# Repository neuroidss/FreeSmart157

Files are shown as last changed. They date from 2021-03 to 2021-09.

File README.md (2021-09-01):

# FreeSmart157

FreeSmartEEG64 prealpha 8 channels assembled
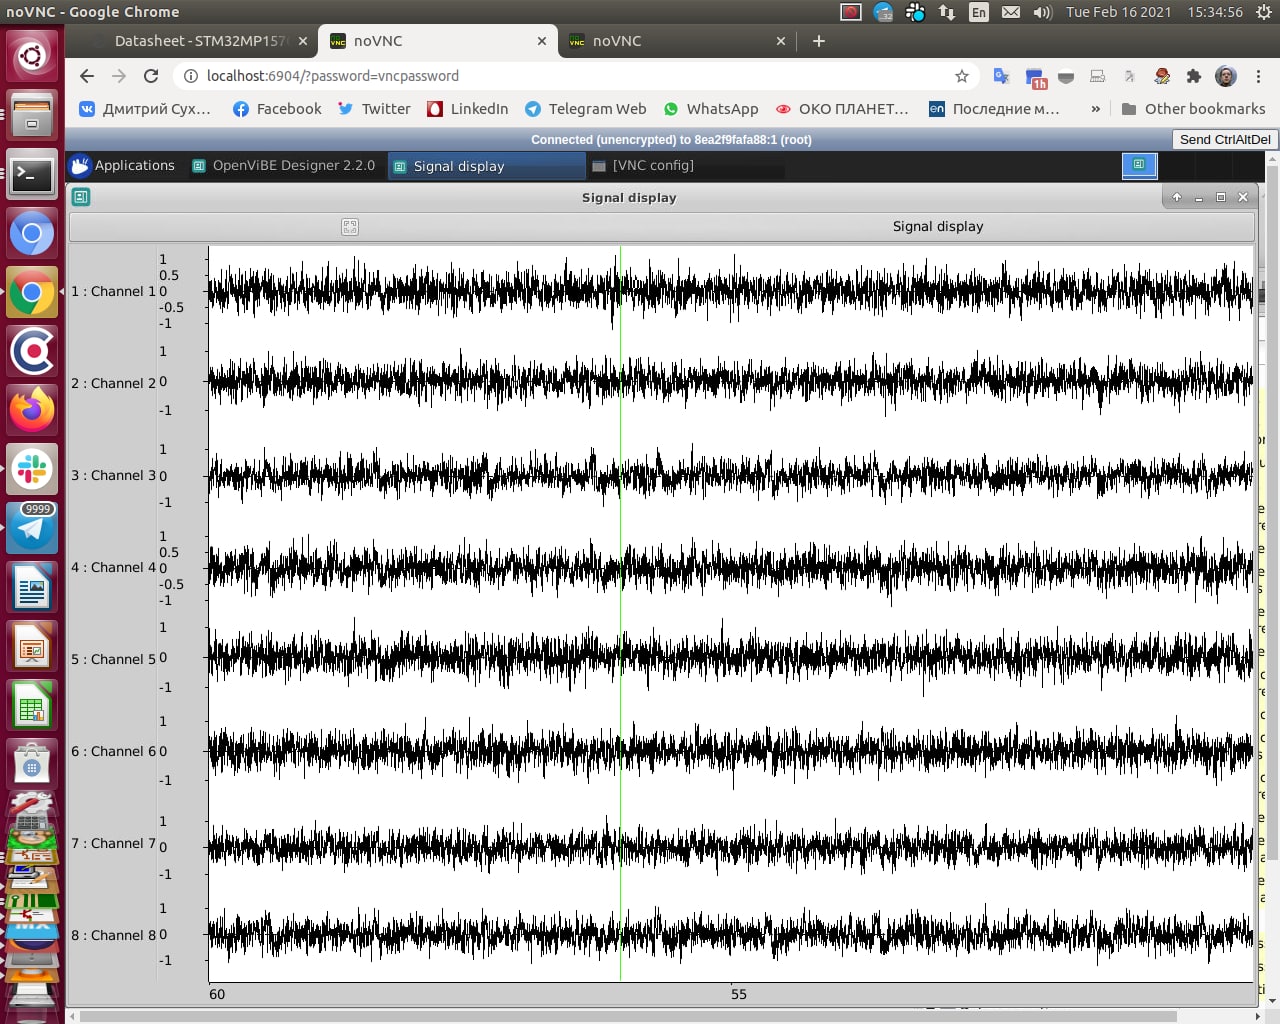
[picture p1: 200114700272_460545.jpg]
FreeSmartEEG64 prealpha 8 channels shorted noise uV AD7771


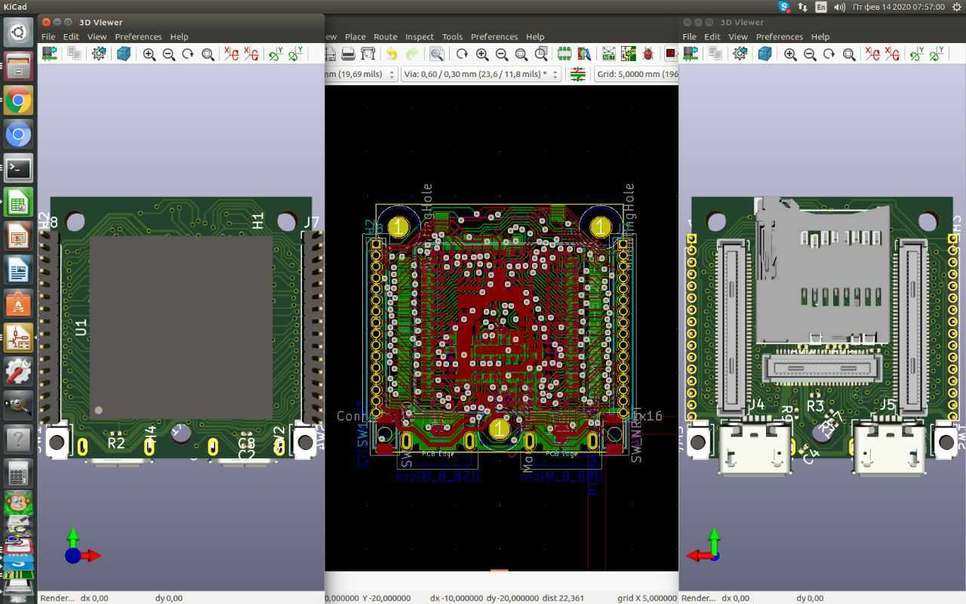
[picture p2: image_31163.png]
FreeSmart157 prealpha module

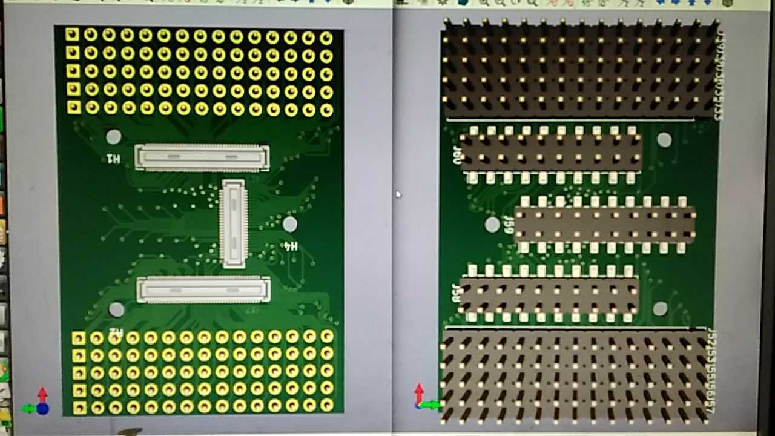
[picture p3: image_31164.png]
FreeSmart157 prealpha devboard


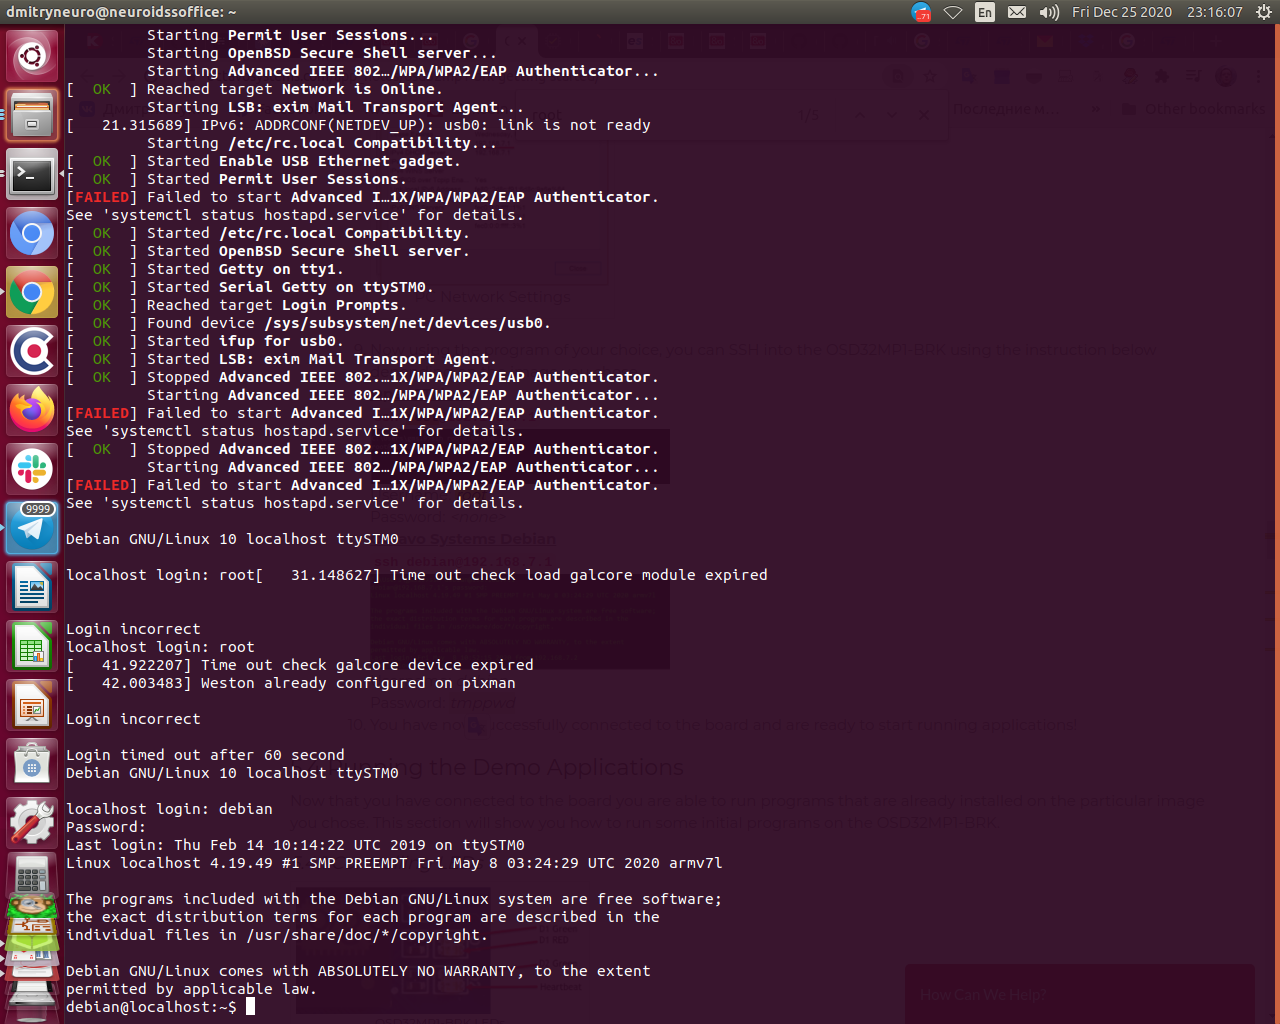
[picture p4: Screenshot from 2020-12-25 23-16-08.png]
FreeSmart157 prealpha debian login

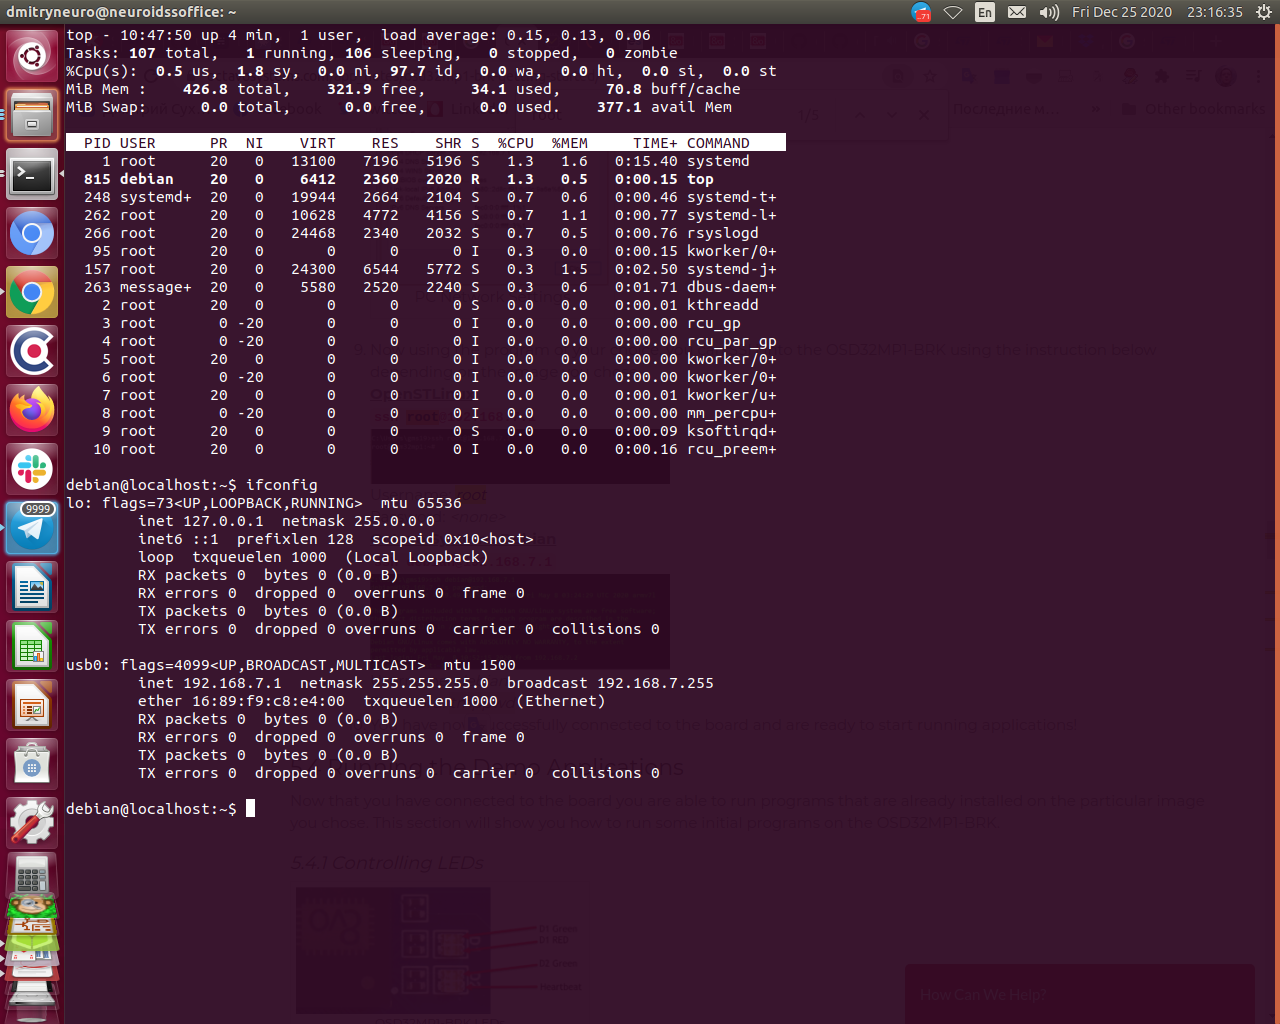
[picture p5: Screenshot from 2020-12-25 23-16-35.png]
FreeSmart157 prealpha top ifconfig


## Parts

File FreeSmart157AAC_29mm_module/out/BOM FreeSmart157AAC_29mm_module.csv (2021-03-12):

Designator | Manufacturer Part Number or Seeed SKU | Qty | Link
SW4,SW3,SW2,SW1 | B3U-1000P | 4 | https://www.digikey.com/product-detail/en/omron-electronics-inc-emc-div/B3U-1000P/SW1020CT-ND/1534357
R9,R13,R12,R10,R4,R3 | RC0201JR-070RL | 6 | https://www.digikey.com/product-detail/en/yageo/RC0201JR-070RL/311-0.0NCT-ND/1949004
P1 | DF40C-50DP-0.4V(51) | 1 | https://www.digikey.com/product-detail/en/hirose-electric-co-ltd/DF40C-50DP-0.4V-51/H11626CT-ND/1969505
U1 | OSD32MP157C-512M-BAA-ES | 1 | https://www.digikey.com/product-detail/en/octavo-systems-llc/OSD32MP157C-512M-BAA-ES/1676-OSD32MP157C-512M-BAA-ES-ND/10481787
J3 | 0473521001 | 1 | https://www.digikey.com/product-detail/en/molex/0473521001/WM3290CT-ND/2405698
C8,C4 | CC0201KRX5R6BB103 | 2 | https://www.digikey.com/product-detail/en/yageo/CC0201KRX5R6BB103/311-1409-1-ND/2833715
R2,R1,R7 | RC0201JR-071KL | 3 | https://www.digikey.com/product-detail/en/yageo/RC0201JR-071KL/311-1KNCT-ND/1949028
C2 | GRM033R60J104KE19D | 1 | https://www.digikey.com/product-detail/en/murata-electronics/GRM033R60J104KE19D/490-3167-1-ND/702708
J5,J4 | USB3076-30-A | 2 | https://www.digikey.com/product-detail/en/gct/USB3076-30-A/2073-USB3076-30-ACT-ND/9859706
J7,J8 | HPH1-B-16-UA | 2 | https://www.digikey.com/product-detail/en/adam-tech/HPH1-B-16-UA/2057-HPH1-B-16-UA-ND/9831568
J2,J1 | DF40C-80DP-0.4V(51) | 2 | https://www.digikey.com/product-detail/en/hirose-electric-co-ltd/DF40C-80DP-0.4V-51/H11632CT-ND/1969511

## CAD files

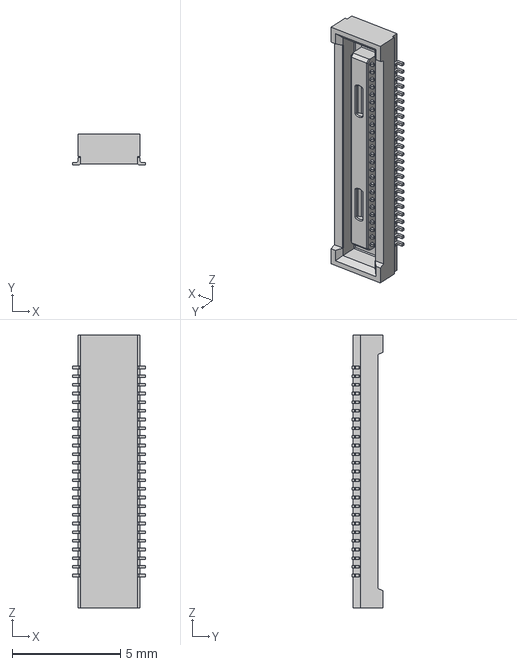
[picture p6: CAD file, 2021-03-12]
FreeSmart157AAC_29mm_devboard_5r_smd/DF40C-50DS-0.4V_51_/DF40C-50DS.stp
3.38 x 1.45 x 12.6 mm

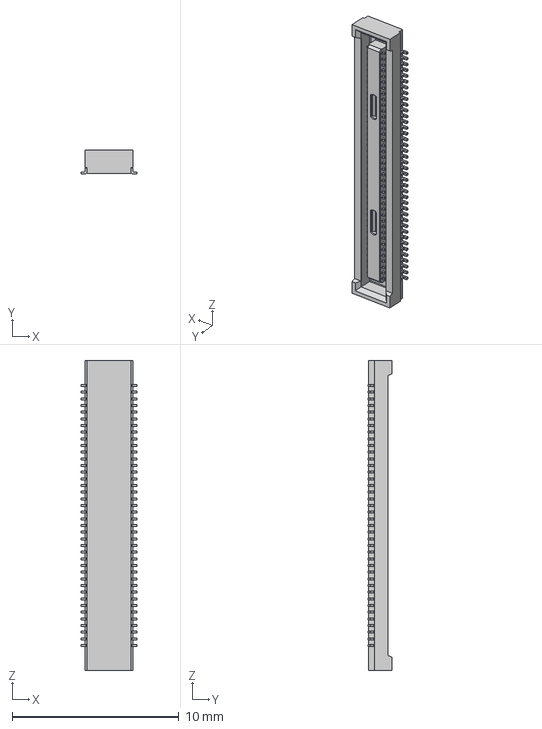
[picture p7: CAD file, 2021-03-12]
FreeSmart157AAC_29mm_devboard_5r_smd/DF40C-80DS-0.4V_51_/DF40C-80DS.stp
3.38 x 1.45 x 18.6 mm

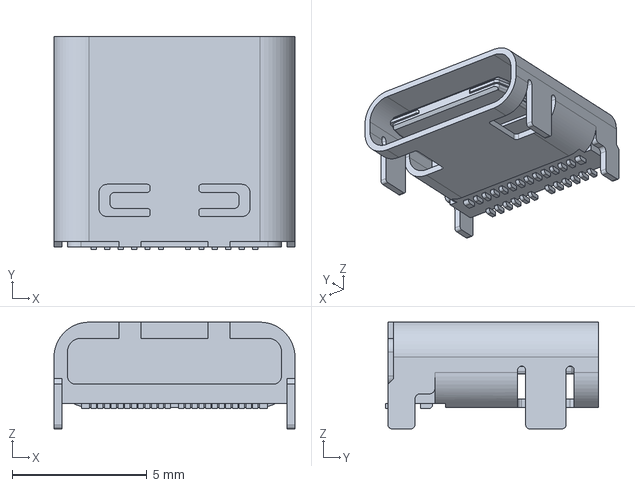
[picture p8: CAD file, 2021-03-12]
FreeSmart157AAC_29mm_devboard_5r_smd/105450-0101/1054500101.stp
8.94 x 7.90 x 3.96 mm

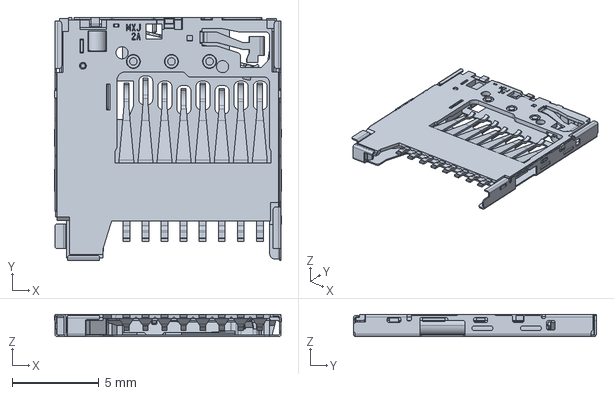
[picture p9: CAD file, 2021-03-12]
FreeSmart157AAC_29mm_devboard_5r_smd/503398-1892/5033981892 (copy).stp
13.1 x 14.0 x 1.28 mm

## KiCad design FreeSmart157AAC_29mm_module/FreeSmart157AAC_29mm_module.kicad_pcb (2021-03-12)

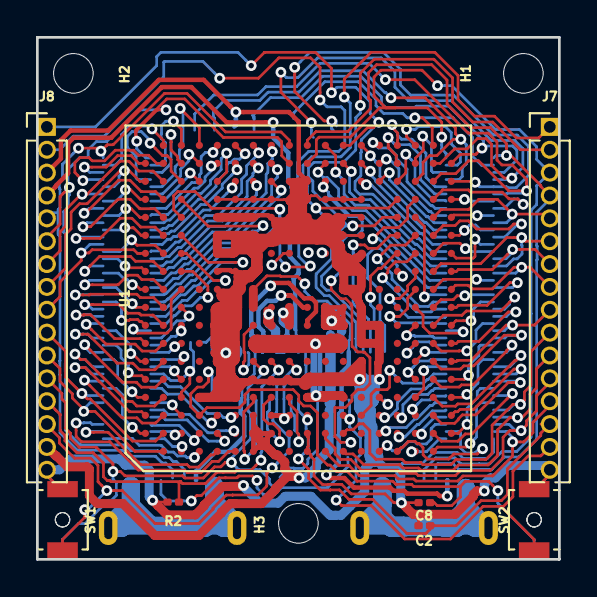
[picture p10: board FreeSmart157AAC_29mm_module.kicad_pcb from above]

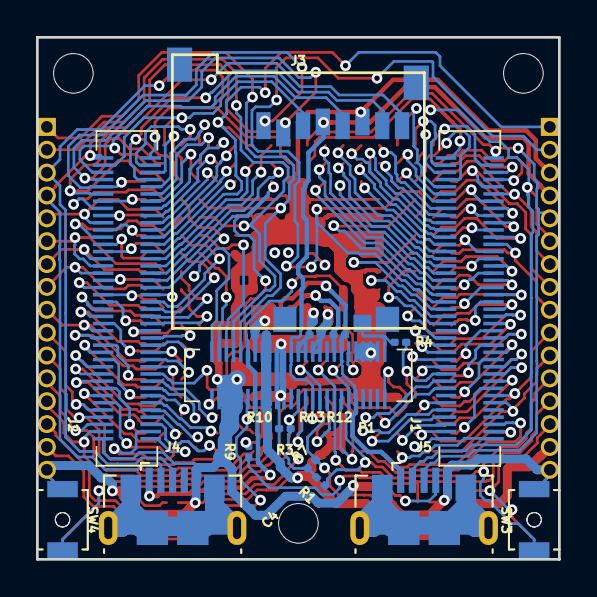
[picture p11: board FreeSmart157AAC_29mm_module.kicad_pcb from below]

Board: 2 copper layers, 29.0 x 29.0 mm, 28 parts (17 on the bottom side), 184 nets.

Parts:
C2: 100n; C_0201_0603Metric
C4, C8: 10n; C_0201_0603Metric
H1, H2, H3: MountingHole; MountingHole_2.2mm_M2
J1, J2: Conn_02x40_Odd_Even; HRS_DF40C-80DS-0.4V(51)
J3: 473521001
J4, J5: USB_B_Micro; USB_Micro-B_GCT_USB3076-30-A
J7, J8: Conn_01x16; PinHeader_1x16_P1.27mm_Vertical
P1: DF40C-50DS-0.4V(51); HRS_DF40C-50DS-0.4V(51)
R1, R2, R7: 1k; R_0201_0603Metric
R3, R4, R9, R10, R12, R13: 0; R_0201_0603Metric
SW1: SW_BOOT0; SW_SPST_B3U-1000P-B
SW2: SW_NRST; SW_SPST_B3U-1000P-B
SW3: SW_BOOT2; SW_SPST_B3U-1000P-B
SW4: SW_PMIC_PONKEYN; SW_SPST_B3U-1000P-B
U1: OSD32MP157C-512M-BAA; OSD32MP15x_BGA-302_19.0x19.0mm_Layout18x18_P1.0mm_Ball0.5mm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

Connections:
3V3: J3.4, J8.4, P1.22, P1.27, U1.H3, U1.J3
5V_VIN: J8.15, P1.33, P1.34, P1.35, P1.36, R10.1, U1.G1, U1.G2, U1.G3, U1.H1, U1.H2
A2: J1.15, U1.A2
A3: J1.19, U1.A3
A4: J1.23, U1.A4
A5: J1.27, U1.A5
A6: J1.31, U1.A6
A7: J1.35, U1.A7
A8: J1.39, U1.A8
A9: J1.43, U1.A9
A10: J1.47, U1.A10
A11: J1.51, U1.A11
A12: J1.55, J8.9, U1.A12
A13: J1.59, U1.A13
A14: J1.63, U1.A14
A15: J1.67, U1.A15
A16: J1.71, J8.8, U1.A16
A17: J1.75, U1.A17
B1: J1.11, J8.11, U1.B1
B2: J1.13, J8.10, U1.B2
B3: J1.17, U1.B3
B4: J1.21, U1.B4
B5: J1.25, U1.B5
B6: J1.29, U1.B6
B7: J1.33, U1.B7
B8: J1.37, U1.B8
B9: J1.41, U1.B9
B10: J1.45, U1.B10
B11: J1.49, U1.B11
B12: J1.53, U1.B12
B13: J1.57, U1.B13
B14: J1.61, U1.B14
B15: J1.65, U1.B15
B16: J1.69, J8.7, U1.B16
B17: J1.73, U1.B17
B18: J1.77, U1.B18
C1: J1.2, U1.C1
C2: J1.4, U1.C2
C3: J1.12, U1.C3
C4: J1.20, R4.2, U1.C4
C5: J1.22, U1.C5
C6: J1.24, U1.C6
C7: J1.26, U1.C7
C8: J1.28, U1.C8
C9: J1.30, U1.C9
C10: J1.32, U1.C10
C11: J1.34, U1.C11
C12: J1.36, U1.C12
C13: J1.38, U1.C13
C14_PG11_UART4_TX: J1.40, J8.2, U1.C14
C15: J1.42, U1.C15
C16: J1.74, U1.C16
C17: J1.76, U1.C17
C18: J1.78, U1.C18
D1: J1.1, U1.D1
D2: J1.6, U1.D2
D16: J1.68, U1.D16
D17: J1.70, U1.D17
D18: J1.72, U1.D18
E1: J1.3, U1.E1
E2: J1.8, U1.E2
E3: J1.16, U1.E3
E16: J1.62, U1.E16
E17: J1.64, U1.E17
E18: J1.66, U1.E18
F1: J1.5, U1.F1
F2: J1.10, U1.F2
F3: J1.18, U1.F3
F16: J1.56, U1.F16
F17: J1.58, U1.F17
F18: J1.60, U1.F18
G6_BOOT2: J8.12, P1.12, R1.1, SW3.1, U1.G6
G16: J1.50, U1.G16
G17: J1.52, U1.G17
G18: J1.54, U1.G18
H6_BOOT1: J8.13, P1.16, R2.1, U1.H6
H16: J1.44, U1.H16
H17: J1.46, U1.H17
H18: J1.48, U1.H18
J6_BOOT0: J8.14, P1.20, R7.1, SW1.1, U1.J6
J17_USB_DM2: J1.80, J5.2, J8.6, U1.J17
J18_USB_DP2: J1.79, J5.3, J8.5, U1.J18
K1_VSSA: C2.2, C4.2, C8.2, J2.2, J3.6, J4.5, J5.5, J7.16, J8.3, J8.16, P1.3, P1.5, P1.7, P1.9, P1.42, P1.44, P1.46, P1.48, R2.2, SW1.2, SW2.2, SW3.2, SW4.2, U1.D4, U1.E4, U1.E5, U1.E6, U1.E7, U1.E8, U1.E9, U1.E10, U1.E11, U1.E12, U1.E13, U1.E14, U1.E15, U1.F4, U1.F5, U1.F6, U1.F7, U1.F8, U1.F9, U1.F10, U1.F11, U1.F12, U1.F13, U1.F14, U1.F15, U1.G5, U1.G11, U1.G12, U1.G13, U1.G14, U1.G15, U1.H5, U1.H13, U1.H14, U1.H15, U1.J5, U1.J13, U1.J14, U1.J15, U1.J16, U1.K1, U1.K2, U1.K5, U1.K13, U1.K14, U1.K15, U1.K16, U1.L5, U1.L13, U1.L14, U1.L15, U1.M5, U1.M10, U1.M11, U1.M12, U1.M13, U1.M14, U1.M15, U1.N5, U1.N6, U1.N7, U1.N8, U1.N9, U1.N10, U1.N11, U1.N12, U1.N13, U1.N14, U1.N15, U1.P5, U1.P6, U1.P7, U1.P8
K3_VBAT: C2.1, J7.14, P1.26, R3.1, U1.K3
K9_OTG_VBUS: P1.15, R12.2, U1.K9
K17_USB_DP1: J2.79, J4.3, J7.3, U1.K17
K18_USB_DM1: J2.80, J4.2, J7.4, U1.K18
L1_ANA0: J2.4, J7.13, U1.L1
L2_ANA1: J2.6, J7.12, U1.L2
L16: J2.45, R9.2, U1.L16
L17: J2.47, U1.L17
L18: J2.49, U1.L18
M1_VDDA: J2.8, J7.11, U1.M1
M2_VREF+: J2.10, J7.10, U1.M2
M3_NRST: C4.1, J7.15, P1.40, SW2.1, U1.M3
M17: J2.51, U1.M17
M18_PB2_UART4_RX: J2.53, J8.1, U1.M18
N3: J2.19, U1.N3
N16_DSI_CKP: J2.55, U1.N16
N17_DSI_D1P: J2.57, U1.N17
N18_DSI_D1N: J2.59, U1.N18
P1: J2.5, U1.P1
P2: J2.11, U1.P2
P3: J2.17, U1.P3
P4_EEPROM_WP: P1.50, U1.P4
P16_DSI_CKN: J2.61, U1.P16
P17_DSI_D0P: J2.63, U1.P17
P18_DSI_D0N: J2.65, U1.P18
PMIC_BSTIN: P1.37, R10.2, U1.L8, U1.L9, U1.M8, U1.M9
PMIC_BSTOUT: P1.23, P1.25, R13.1, U1.J8, U1.J9
PMIC_LDO1: P1.24, U1.J4
PMIC_LDO2: P1.14, U1.G4
PMIC_LDO5: P1.11, U1.G8
PMIC_LDO6: P1.18, U1.H4
PMIC_PONKEYN: C8.1, P1.2, SW4.1, U1.D3
PMIC_SWIN: P1.19, P1.21, R13.2, U1.H8, U1.H9
PMIC_SWOUT: J4.1, P1.38, P1.39, U1.G9, U1.G10
PMIC_VBUSOTG: J5.1, P1.10, P1.13, R12.1, U1.K8
R1: J2.3, U1.R1
R2: J2.9, U1.R2
R3: J2.15, U1.R3
R11_NJTRST: P1.49, U1.R11
R12_JTDO-TRACESWO: P1.47, U1.R12
R13_JTDI: P1.45, U1.R13
R14_JTMS-SWDIO: J7.2, P1.43, U1.R14
R15_JTCK-SWCLK: J7.1, P1.41, U1.R15
R16: J2.67, U1.R16
R17: J2.69, U1.R17
R18: J2.71, U1.R18
SDMMC1_DETECT: J3.9, P1.1, R4.1
T1: J2.1, U1.T1
T2: J2.7, U1.T2
T3: J2.13, U1.T3
T4: J2.21, U1.T4
T5: J2.23, U1.T5
T6: J2.25, U1.T6
T7: J2.27, U1.T7
T8: J2.29, U1.T8
T9: J2.31, U1.T9
T10: J2.33, U1.T10
T11: J2.35, U1.T11
T12: J2.37, U1.T12
T13: J2.39, U1.T13
T14: J2.41, U1.T14
T15: J2.43, U1.T15
T16_PC8_SDMMC1_D0: J2.73, J3.7, U1.T16
T17: J2.75, U1.T17
T18: J2.77, U1.T18
U1: J2.12, U1.U1
U2: J2.14, U1.U2
U3: J2.18, U1.U3
U4: J2.22, U1.U4
U5: J2.26, U1.U5
U6: J2.30, U1.U6
U7: J2.34, U1.U7
U8: J2.38, U1.U8
U9: J2.42, U1.U9
U10: J2.46, U1.U10
U11: J2.50, J7.6, U1.U11
U12: J2.54, U1.U12
U13: J2.58, U1.U13
U14: J2.62, J7.5, U1.U14
U15: J2.66, U1.U15
U16_PC9_SDMMC1_D1: J2.70, J3.8, U1.U16
U17_PC11_SDMMC1_D3: J2.74, J3.2, U1.U17
U18_PD2_SDMMC1_CMD: J2.78, J3.3, U1.U18
USBID2: J5.4, R9.1
V2: J2.16, U1.V2
V3: J2.20, U1.V3
V4: J2.24, U1.V4
V5: J2.28, U1.V5
V6: J2.32, J7.9, U1.V6
V7: J2.36, U1.V7
V8: J2.40, U1.V8
V9: J2.44, U1.V9
V10: J2.48, J7.8, U1.V10
V11: J2.52, J7.7, U1.V11
V12: J2.56, U1.V12
V13: J2.60, U1.V13
V14: J2.64, U1.V14
V15: J2.68, U1.V15
V16_PC10_SDMMC1_D2: J2.72, J3.1, U1.V16
V17_PC12_SDMMC1_CK: J2.76, J3.5, U1.V17
VDD: P1.29, P1.30, P1.31, P1.32, R1.2, R3.2, R7.2, U1.G7, U1.H7, U1.J7, U1.K4, U1.K7, U1.L4, U1.L7, U1.M4, U1.M7

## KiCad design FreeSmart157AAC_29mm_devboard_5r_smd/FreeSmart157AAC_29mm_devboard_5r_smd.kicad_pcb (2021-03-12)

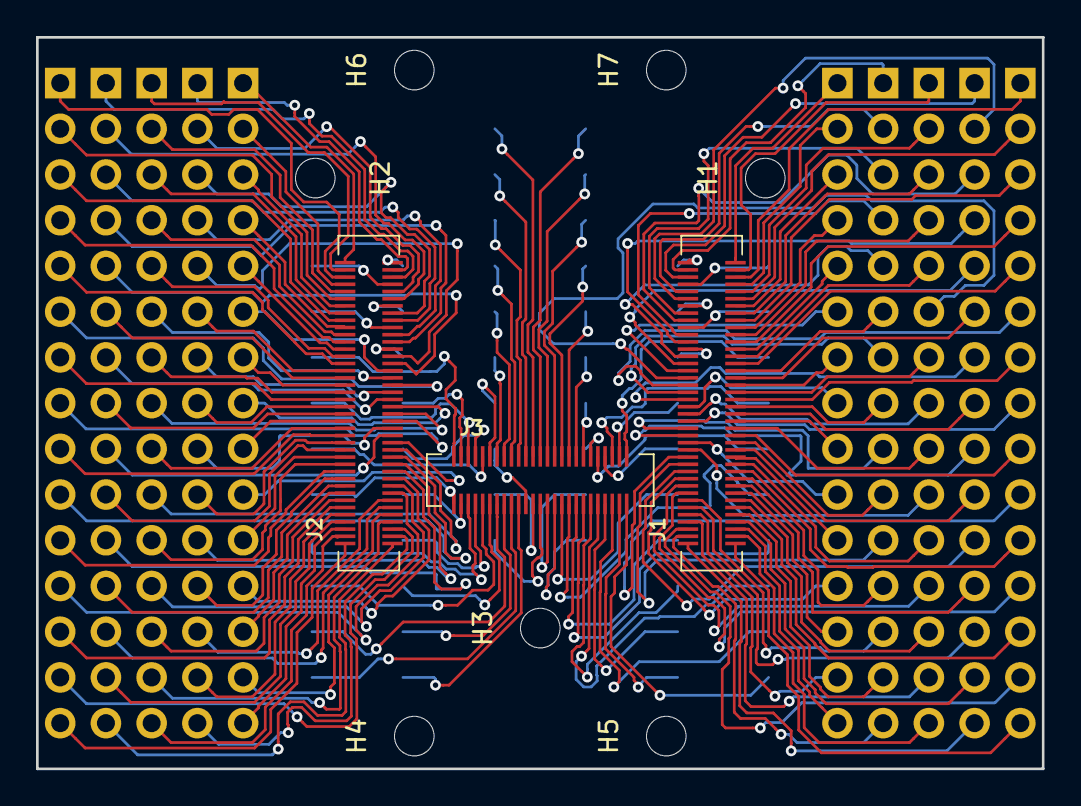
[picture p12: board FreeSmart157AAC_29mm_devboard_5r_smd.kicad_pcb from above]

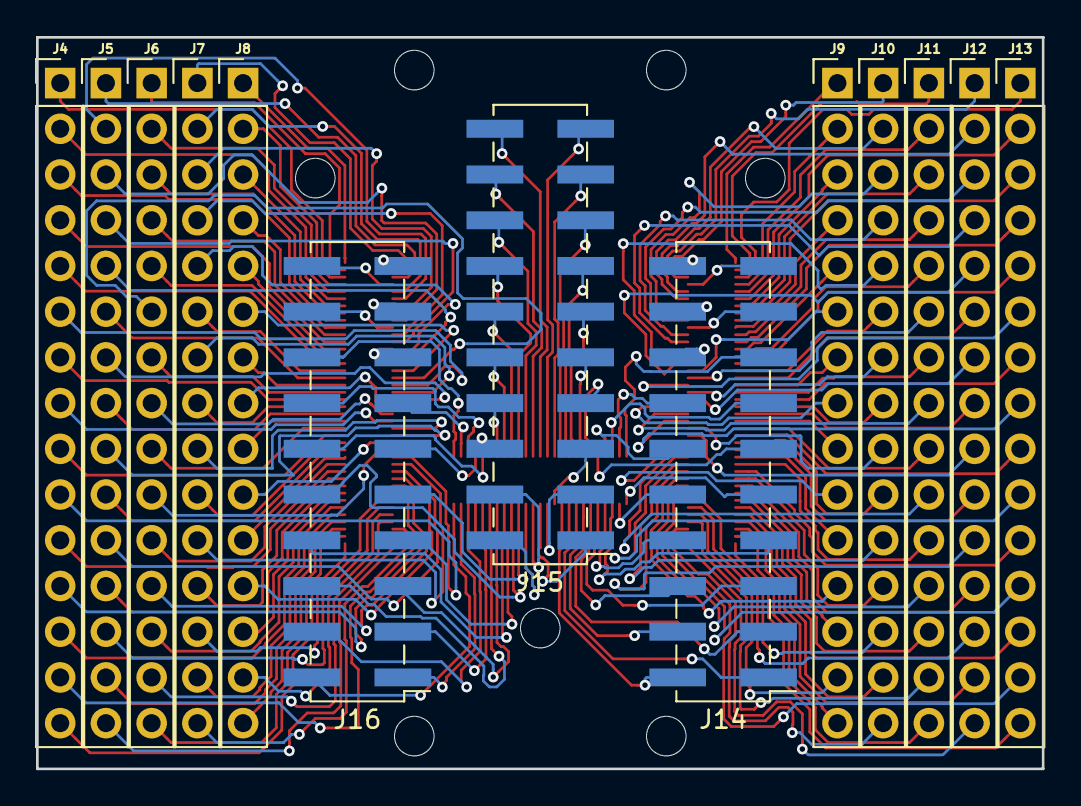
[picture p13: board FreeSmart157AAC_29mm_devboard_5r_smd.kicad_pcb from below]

Board: 2 copper layers, 55.9 x 40.6 mm, 23 parts (13 on the bottom side), 210 nets.

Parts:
H1, H2, H3, H4, H5, H6, H7: MountingHole; MountingHole_2.2mm_M2
J1, J2: Conn_02x40_Odd_Even; HRS_DF40C-80DS-0.4V(51)
J3: Conn_02x25_Odd_Even; HRS_DF40C-50DS-0.4V(51)
J4, J5, J6, J7, J8, J9, J10, J11, J12, J13: Conn_01x15; PinHeader_1x15_P2.54mm_Vertical
J14, J15, J16: Conn_02x10_Odd_Even; PinHeader_2x10_P2.54mm_Vertical_SMD

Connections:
A1: J2.79, J14.20
A2: J2.80, J9.1
A3: J2.77, J10.1
A4: J2.78, J11.1
A5: J2.75, J12.1
A6: J2.76, J13.1
A7: J2.73, J14.19
A8: J2.74, J9.2
A9: J2.71, J10.2
A10: J2.72, J11.2
A11: J2.69, J12.2
A12: J2.70, J13.2
A13: J2.67, J14.18
A14: J2.68, J9.3
A15: J2.65, J10.3
A16: J2.66, J11.3
A17: J2.63, J12.3
A18: J2.64, J13.3
A19: J2.61, J14.17
A20: J2.62, J9.4
A21: J2.59, J10.4
A22: J2.60, J11.4
A23: J2.57, J12.4
A24: J2.58, J13.4
A25: J2.55, J14.16
A26: J2.56, J9.5
A27: J2.53, J10.5
A28: J2.54, J11.5
A29: J2.51, J12.5
A30: J2.52, J13.5
A31: J2.49, J9.6
A32: J2.50, J10.6
A33: J2.47, J11.6
A34: J2.48, J12.6
A35: J2.45, J13.6
A36: J2.46, J9.7
A37: J2.43, J10.7
A38: J2.44, J11.7
A39: J2.41, J12.7
A40: J2.42, J13.7
A41: J2.39, J9.8
A42: J2.40, J10.8
A43: J2.37, J11.8
A44: J2.38, J12.8
A45: J2.35, J13.8
A46: J2.36, J9.9
A47: J2.33, J10.9
A48: J2.34, J11.9
A49: J2.31, J12.9
A50: J2.32, J13.9
A51: J2.29, J9.10
A52: J2.30, J10.10
A53: J2.27, J11.10
A54: J2.28, J12.10
A55: J2.25, J13.10
A56: J2.26, J9.11
A57: J2.23, J10.11
A58: J2.24, J11.11
A59: J2.21, J12.11
A60: J2.22, J13.11
A61: J2.19, J9.12
A62: J2.20, J10.12
A63: J2.17, J11.12
A64: J2.18, J12.12
A65: J2.15, J13.12
A66: J2.16, J9.13
A67: J2.13, J10.13
A68: J2.14, J11.13
A69: J2.11, J12.13
A70: J2.12, J13.13
A71: J2.9, J9.14
A72: J2.10, J10.14
A73: J2.7, J11.14
A74: J2.8, J12.14
A75: J2.5, J13.14
A76: J2.6, J9.15
A77: J2.3, J10.15
A78: J2.4, J11.15
A79: J2.1, J12.15
A80: J2.2, J13.15
B1: J1.80, J16.19
B2: J1.79, J8.1
B3: J1.78, J7.1
B4: J1.77, J6.1
B5: J1.76, J5.1
B6: J1.75, J4.1
B7: J1.74, J16.20
B8: J1.73, J8.2
B9: J1.72, J7.2
B10: J1.71, J6.2
B11: J1.70, J5.2
B12: J1.69, J4.2
B13: J1.68, J16.17
B14: J1.67, J8.3
B15: J1.66, J7.3
B16: J1.65, J6.3
B17: J1.64, J5.3
B18: J1.63, J4.3
B19: J1.62, J16.18
B20: J1.61, J8.4
B21: J1.60, J7.4
B22: J1.59, J6.4
B23: J1.58, J5.4
B24: J1.57, J4.4
B25: J1.56, J16.15
B26: J1.55, J8.5
B27: J1.54, J7.5
B28: J1.53, J6.5
B29: J1.52, J5.5
B30: J1.51, J4.5
B31: J1.50, J8.6
B32: J1.49, J7.6
B33: J1.48, J6.6
B34: J1.47, J5.6
B35: J1.46, J4.6
B36: J1.45, J8.7
B37: J1.44, J7.7
B38: J1.43, J6.7
B39: J1.42, J5.7
B40: J1.41, J4.7
B41: J1.40, J8.8
B42: J1.39, J7.8
B43: J1.38, J6.8
B44: J1.37, J5.8
B45: J1.36, J4.8
B46: J1.35, J8.9
B47: J1.34, J7.9
B48: J1.33, J6.9
B49: J1.32, J5.9
B50: J1.31, J4.9
B51: J1.30, J8.10
B52: J1.29, J7.10
B53: J1.28, J6.10
B54: J1.27, J5.10
B55: J1.26, J4.10
B56: J1.25, J8.11
B57: J1.24, J7.11
B58: J1.23, J6.11
B59: J1.22, J5.11
B60: J1.21, J4.11
B61: J1.20, J8.12
B62: J1.19, J7.12
B63: J1.18, J6.12
B64: J1.17, J5.12
B65: J1.16, J4.12
B66: J1.15, J8.13
B67: J1.14, J7.13
B68: J1.13, J6.13
B69: J1.12, J5.13
B70: J1.11, J4.13
B71: J1.10, J8.14
B72: J1.9, J7.14
B73: J1.8, J6.14
B74: J1.7, J5.14
B75: J1.6, J4.14
B76: J1.5, J8.15
B77: J1.4, J7.15
B78: J1.3, J6.15
B79: J1.2, J5.15
B80: J1.1, J4.15
C1: J3.2, J14.15
C2: J3.1, J14.9
C3: J3.4, J14.14
C4: J3.3, J14.10
C5: J3.6, J14.13
C6: J3.5, J14.7
C7: J3.8, J14.12
C8: J3.7, J14.8
C9: J3.10, J14.11
C10: J3.9, J14.5
C11: J3.12, J15.7
C12: J3.11, J14.6
C13: J3.14, J15.9
C14: J3.13, J14.3
C15: J3.16, J15.11
C16: J3.15, J14.4
C17: J3.18, J15.13
C18: J3.17, J14.1
C19: J3.20, J15.15
C20: J3.19, J14.2
C21: J3.22, J15.17
C22: J3.21, J15.5
C23: J3.24, J15.19
C24: J3.23, J15.3
C25: J3.26, J15.20
C26: J3.25, J15.1
C27: J3.28, J15.18
C28: J3.27, J15.4
C29: J3.30, J15.16
C30: J3.29, J15.2
C31: J3.32, J15.14
C32: J3.31, J16.9
C33: J3.34, J15.12
C34: J3.33, J16.10
C35: J3.36, J15.10
C36: J3.35, J16.7
C37: J3.38, J15.8
C38: J3.37, J16.8
C39: J3.40, J15.6
C40: J3.39, J16.5
C41: J3.42, J16.12
C42: J3.41, J16.6
C43: J3.44, J16.11
C44: J3.43, J16.3
C45: J3.46, J16.14
C46: J3.45, J16.4
C47: J3.48, J16.13
C48: J3.47, J16.1
C49: J3.50, J16.16
C50: J3.49, J16.2
